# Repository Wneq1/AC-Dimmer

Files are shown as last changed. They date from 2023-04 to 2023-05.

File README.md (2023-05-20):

# AC-Dimmer

Power regulator for arduino 

In today's project, we will focus on building a power regulator using an Arduino microcontroller and a thyristor. Power regulators are commonly used to control the amount of electrical energy supplied to loads such as lamps, heaters, or motors, in order to adjust their brightness, temperature, or speed. By building your own power regulator using Arduino and a thyristor, you can create a cost-effective and customized solution for controlling AC loads in DIY projects or home automation systems. IF you wish to built one by yourselfe in this file, you can find a finished project in KiCad and short code in Arduino.

WARNING: THIS PROJECT INVOLVES HIGH VOLTAGES THAT CAN BE DANGEROUS TO LIFE AND HEALTH. 
YOU PERFORM THIS PROJECT AT YOUR OWN RISK AND RESPONSIBILITY.

To complete this project you will need:
Arduino or other microcontroller
* Fuse
* Resistors
    * 68k x2
    * 33k x2
    * 360 x1
    * 330 x2
    * 10k x5
    * 39 x1
* Capacitors
    * 0.01uF x1
    * 100nF x1
    * 25uF x1
* Optocoupler PC817
* Hi-link
* LM7805 (5V regulator)
* LED
* Optotriac MOC3041
* Pushbuttons
* OLED Display
* Thyristor BT138

Our system consists of several modules: 
* power module
* actuator module
* measurement module
* logic module



Short description of this project:

The power module is designed to deliver a stable 5V due to the current drawn by the circuit. I decided to use a pre-made Hi-Link power module, but if there is no need to support the interface (display buttons), a transformerless power supply can be used. The type of regulation used in the project is phase regulation. 
The disadvantage of this type of control is radio-electric interference, which appears when working with high-power receivers.

The measurement module consists of an optoelectronic component that is designed to detect the zero crossing of the input signal and then send information to the control module.

The output module consists of a triac that is turned on for a specified period by the microcontroller. In case the circuit needs to handle inductive loads, an additional capacitor and resistor should be added (refer to the datasheet).

The logic module consists of an Arduino microcontroller (or any other microcontroller that supports interrupts). The microcontroller operates based on interrupts (if zero crossing is detected, the microcontroller interrupts the currently running task and performs the interrupt function, i.e. turns on a timer that counts how long the output module should be turned on, and then turns off the triac).

Our device has 4 buttons, of which only 3 are used. One button is used to increase the power, the second to decrease it, and the third is the so-called "latch" button. There is also an LED used to indicate whether the latch is active. If the LED is on (button active), we can edit the power value by increasing or decreasing it. However, if the LED is off, we cannot edit the power value (even if we press other buttons, the power value will not change).

In AC-powered devices, power is closely related to the area under the sine wave applied to the input of our controlled system (e.g., a light bulb), and it is this area that can be regulated. However, in order to do this, we need a reference point. Since the signal present in the power socket is sinusoidal in nature, our reference point will be the zero crossing of the waveform, which will define how long our load will be energized. The longer the duration, the higher the power.

Now, let's do some math. Let's say the frequency of the power grid is 50 Hz, which means the period is f=1/T T=1/f=1/50=20[ms]. In each cycle, there are two peak values of the sine wave, so we reach the peak every 10 ms. If we manage to turn on the light bulb at the very beginning, it will receive 100% of the available power. If we turn it on halfway through (5 ms), it will receive 50% of the power, and if we turn it on towards the end of the 10 ms period, it will remain off (0% power).

Short description:

The blue waveform illustrates the mains voltage, while the orange waveform represents the response of the circuit to the previously applied power (response of the triac).
The waveform appearance for 100% power:



The waveform appearance for 50% power:



The waveform appearance for 25% power:



Below are some illustrative photos and link to video prezentation:



Short presentation on YouTube:
https://www.youtube.com/watch?v=zxgGnlvmVzU

In the files, you can also find another version of the Arduino code called 'Final Version,' where the only change is the selection mode of the controller values. However, the operating principle remains the same as in the previous version. You can find the link below.
Short presentation of Finall Version on YouTube:
https://www.youtube.com/watch?v=YGqYrHkOaR0

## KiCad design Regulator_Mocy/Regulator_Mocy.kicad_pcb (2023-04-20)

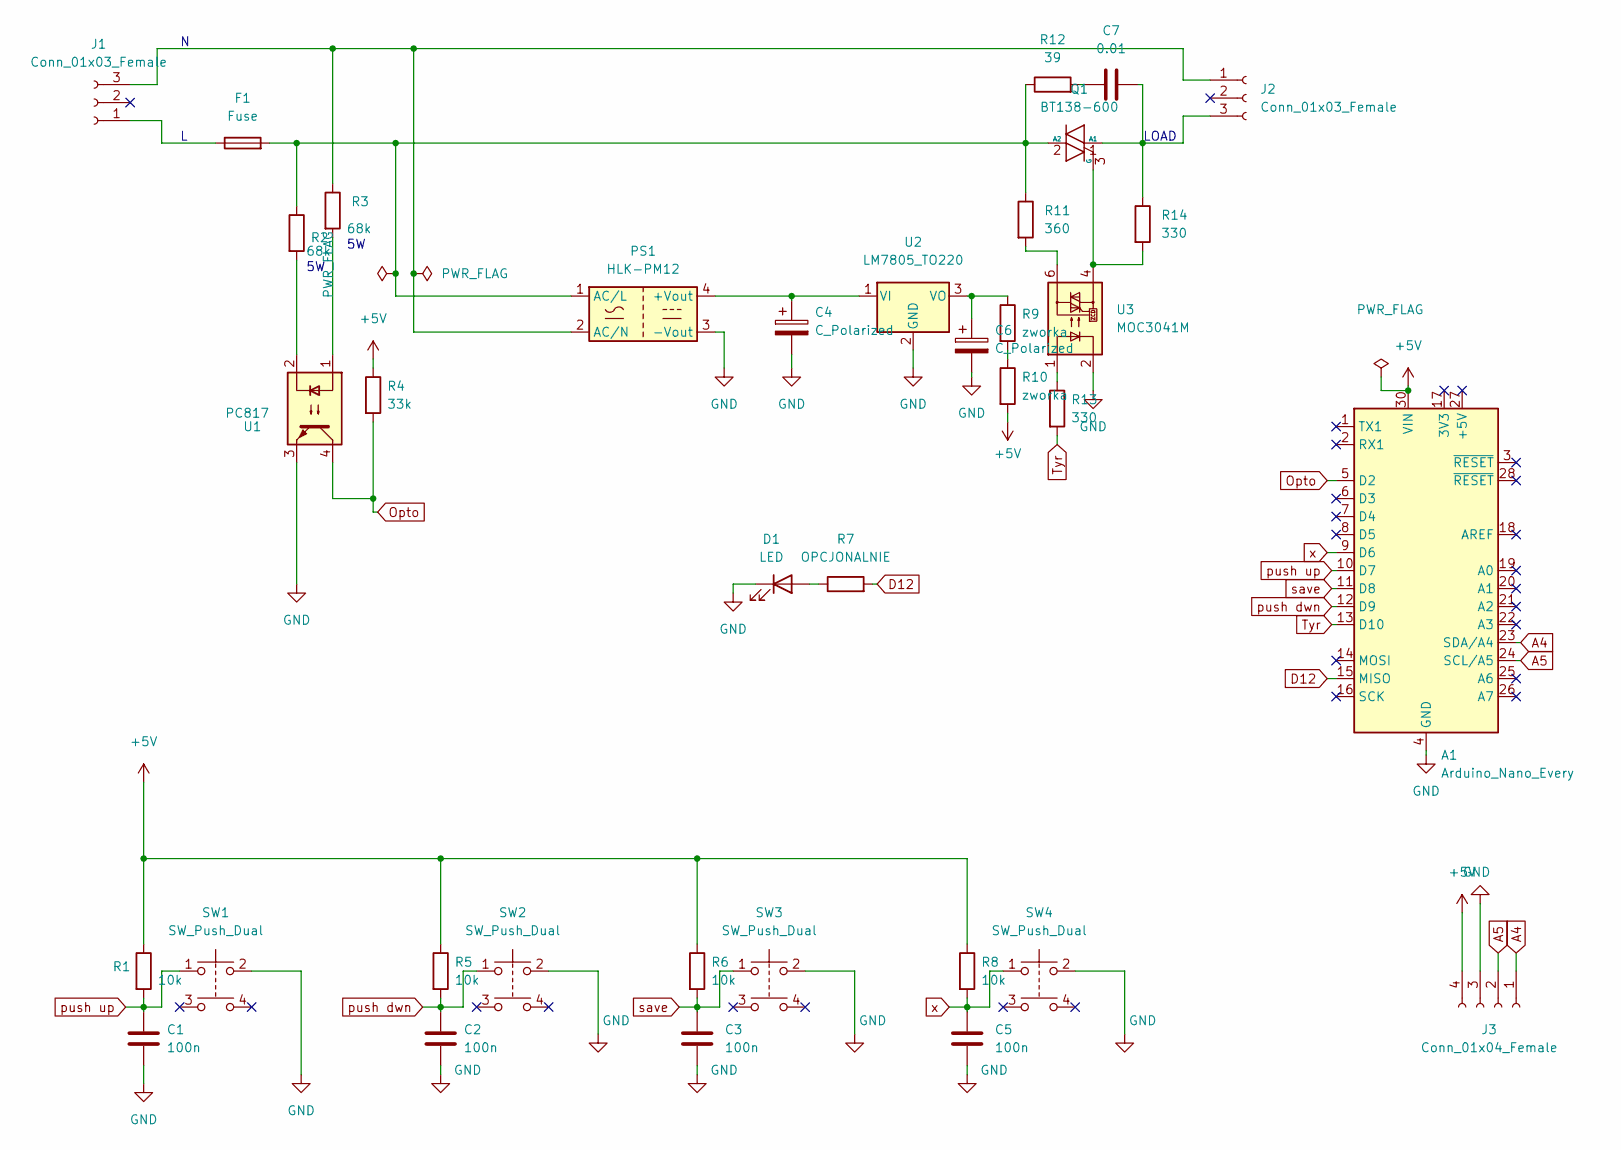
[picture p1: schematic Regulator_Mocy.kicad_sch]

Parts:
A1: Arduino_Nano_Every; Arduino_Nano
C1, C2, C3, C5: 100n; C_Axial_L3.8mm_D2.6mm_P10.00mm_Horizontal
C4, C6: C_Polarized; CP_Radial_D8.0mm_P3.80mm
C7: 0.01; C_Rect_L24.0mm_W10.1mm_P22.50mm_MKT
D1: LED; LED_D5.0mm
F1: Fuse; Fuseholder_Cylinder-5x20mm_Schurter_0031_8201_Horizontal_Op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
J1, J2: Conn_01x03_Female; Molex_KK-396_A-41792-0003_1x03_P3.96mm_Horizontal
J3: Conn_01x04_Female; PinHeader_1x04_P2.54mm_Vertical
PS1: HLK-PM12; Converter_ACDC_HiLink_HLK-PMxx
Q1: BT138-600; TO-220-3_Vertical
R1, R5, R6, R8: 10k; R_Axial_DIN0207_L6.3mm_D2.5mm_P10.16mm_Horizontal
R2, R3: 68k; R_Axial_Power_L25.0mm_W9.0mm_P27.94mm
R4: 33k; R_Axial_DIN0207_L6.3mm_D2.5mm_P10.16mm_Horizontal
R7: OPCJONALNIE; R_Axial_DIN0207_L6.3mm_D2.5mm_P10.16mm_Horizontal
R9, R10: zworka; R_Axial_DIN0204_L3.6mm_D1.6mm_P5.08mm_Vertical
R11: 360; R_Axial_DIN0207_L6.3mm_D2.5mm_P10.16mm_Horizontal
R12: 39; R_Axial_Power_L25.0mm_W9.0mm_P27.94mm
R13, R14: 330; R_Axial_DIN0207_L6.3mm_D2.5mm_P10.16mm_Horizontal
SW1, SW2, SW3, SW4: SW_Push_Dual; SW_PUSH_6mm_H7.3mm
U1: PC817; DIP-4_W7.62mm
U2: LM7805_TO220; TO-220-3_Vertical
U3: MOC3041M; DIP-6_W7.62mm

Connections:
+5V: A1.30 (VIN), J3.4, R1.1, R4.1, R5.1, R6.1, R8.1, R10.2
A4: A1.23 (SDA/A4), J3.1
A5: A1.24 (SCL/A5), J3.2
D12: A1.15 (MISO), R7.2
GND: A1.4 (GND), A1.29 (GND), C1.2, C2.2, C3.2, C4.2, C5.2, C6.2, D1.1 (K), J3.3, PS1.3 (-Vout), SW1.2, SW2.2, SW3.2, SW4.2, U1.3, U2.2 (GND), U3.2
unnamed: C4.1, PS1.4 (+Vout), U2.1 (VI)
unnamed: C6.1, R9.1, U2.3 (VO)
unnamed: C7.1, R12.2
unnamed: C7.2, J2.3, Q1.1 (A1), R14.1
unnamed: D1.2 (A), R7.1
unnamed: F1.1, J1.1
unnamed: F1.2, PS1.1 (AC/L), Q1.2 (A2), R2.1, R11.1, R12.1
unnamed: J1.3, J2.1, PS1.2 (AC/N), R3.1
unnamed: Q1.3 (G), R14.2, U3.4
unnamed: R2.2, U1.2
unnamed: R3.2, U1.1
unnamed: R9.2, R10.1
unnamed: R11.2, U3.6
unnamed: R13.1, U3.1
Opto: A1.5 (D2), R4.2, U1.4
Tyr: A1.13 (D10), R13.2
push dwn: A1.12 (D9), C2.1, R5.2, SW2.1
push up: A1.10 (D7), C1.1, R1.2, SW1.1
save: A1.11 (D8), C3.1, R6.2, SW3.1
x: A1.9 (D6), C5.1, R8.2, SW4.1

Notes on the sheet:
LOAD

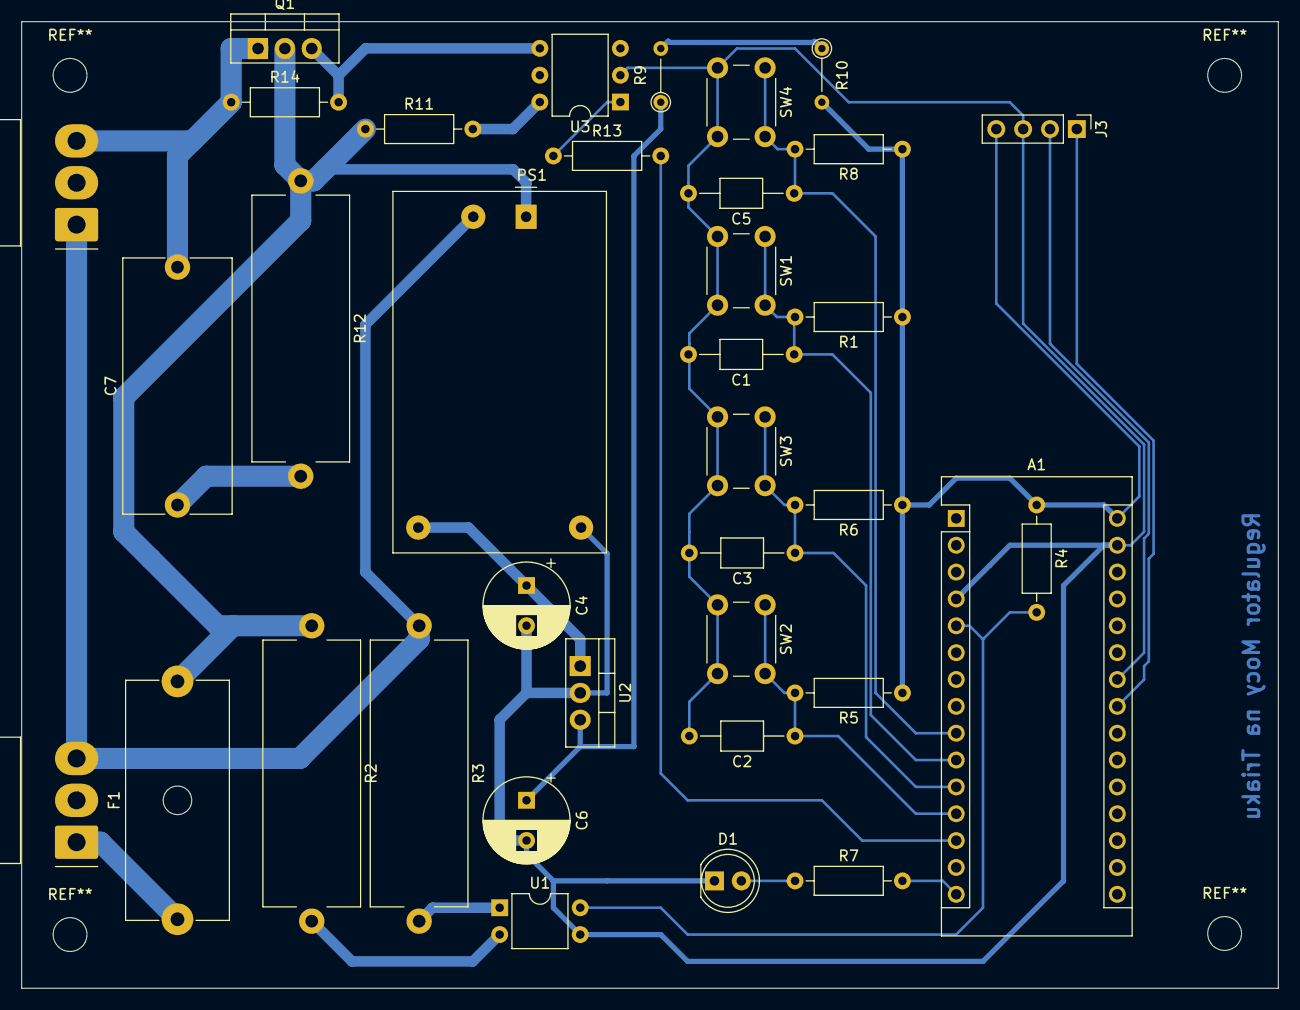
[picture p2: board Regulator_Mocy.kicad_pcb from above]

Board: 2 copper layers, 118.9 x 91.4 mm, 36 parts (0 on the bottom side), 25 nets.

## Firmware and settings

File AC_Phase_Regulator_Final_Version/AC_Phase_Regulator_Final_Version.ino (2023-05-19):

#include <TimerOne.h>
#include <Wire.h>
#include <Adafruit_GFX.h>
#include <Adafruit_SSD1306.h>

#define OLED_RESET 4
Adafruit_SSD1306 display(OLED_RESET);

int LED = 12;           // signalization LED
int previous_save_value = 0;
int set_value = 0;
int x = 128;

int add_button = 9;
int subtract_button = 7;
int save_button = 8;
int save_button_state = HIGH;
int last_save_button_state = HIGH;
bool save = false;

int Triac = 10; //AC Load

int inc = 1;

volatile int i = 0;
volatile boolean zero_crossing = false; //zero crosing value
int value = 128;           //value for operating triac
int frequency_step = 75;   // 50Hz -> 75 || 60Hz -> 65

/* It is calculated based on the frequency of the power supply and the desired brightness level.
 *
 * The program relies on two zero-crossing points during one cycle, which is either for 120Hz and 60Hz or for 100Hz and 50Hz.
 *
 * To determine the frequency step, divide the duration of a full signal half-cycle in microseconds by the number of brightness levels per step.
 *
 * (120Hz = 8,333μs) -> 128 steps yield 65μs
 * (100Hz = 10,000μs) -> 128 steps yield 75μs
 */



void setup() {
  Serial.begin(9600);
  pinMode(Triac, OUTPUT);
  pinMode(LED, OUTPUT);
  pinMode(add_button, INPUT_PULLUP);
  pinMode(subtract_button, INPUT_PULLUP);
  pinMode(save_button, INPUT_PULLUP);

  attachInterrupt(0, detect_zero_crossing, RISING);   // zero crossing detector on pin numb. 2
  Timer1.initialize(frequency_step);
  Timer1.attachInterrupt(check_value, frequency_step);

  display.begin(SSD1306_SWITCHCAPVCC, 0x3C);
  display.display();
  display.clearDisplay();
}

void detect_zero_crossing() {
  zero_crossing = true;
  i = 0;
  digitalWrite(Triac, LOW);
}

void check_value() {
  if (zero_crossing == true) {
    if (i >= value) {
      digitalWrite(Triac, HIGH);
      i = 0;
      zero_crossing = false;
    }
    else {
      i++;
    }
  }
}

int AddButton(int add_button) {
  if (digitalRead(add_button) == LOW) {
    if (x < 128) {
      x = x + 1;
      delay(10);
    }
  }
  return x;
}

int SubtractButton(int subtract_button) {
  if (digitalRead(subtract_button) == LOW) {
    if (value > 0) {
      x = x - 1;
      delay(10);
    }
  }
  return x;
}

bool SaveButton(int save_button) {
  save_button_state = digitalRead(save_button);
  if (save_button_state == LOW && last_save_button_state == HIGH) {
    save = !save;
  }
  last_save_button_state = save_button_state;
  delay(10);
  return save;
}

void test() {
  value += inc;
  if ((value >= 128) || (value <= 0))
    inc *= -1;
  delay(20);
}

void loop() {
  int save_button_state = digitalRead(save_button);

  if (save_button_state == LOW && last_save_button_state == HIGH) {
    save = !save;
    if (save == 0) {
      value = x;
    }
  }

  last_save_button_state = save_button_state;

  if (save == 1) {
    digitalWrite(LED, HIGH);
    
    x = AddButton(add_button);
    x = SubtractButton(subtract_button);

    display.clearDisplay();
    display.setTextSize(3);
    display.setTextColor(WHITE);
    display.setCursor(40, 0);
    display.print(map(x, 128, 0, 0, 100));
    display.print("%");

    display.setTextSize(1);
    display.setTextColor(WHITE);
    display.setCursor(20, 25);
    display.print("Phase regulation");
    display.display();
  } else if (save == 0 && set_value == 0) {
    for (int i = 0; i < x; i++) {
      value++;
    }
    set_value = 1;

    display.clearDisplay();
    display.setTextSize(3);
    display.setTextColor(WHITE);
    display.setCursor(40, 0);
    display.print(map(x, 128, 0, 0, 100));
    display.print("%");

    display.setTextSize(1);
    display.setTextColor(WHITE);
    display.setCursor(20, 25);
    display.print("Phase regulation");
    display.display();
  }

  if (save == 0) {
    digitalWrite(LED, HIGH);
    delay(500);
    digitalWrite(LED, LOW);
    delay(500);
  }

  Serial.println("X " + String(x) + " Value " + value);
}

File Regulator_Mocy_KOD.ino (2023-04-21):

#include <TimerOne.h>                    // library for phase control

#include <Wire.h>                         // display initialization
#include <Adafruit_GFX.h>
#include <Adafruit_SSD1306.h>
#define OLED_RESET 4
Adafruit_SSD1306 display(OLED_RESET);
#if (SSD1306_LCDHEIGHT != 64)
//#error("Height incorrect, please fix Adafruit_SSD1306.h!");
#endif/

int LED = 12;

int button_add = 9;                   // button to increase power

int button_subtract = 7;                 // button to decrease power

int button_save = 8;                   // save button
int button_save_state = HIGH;
int last_button_save_state = HIGH;
int save = 0;

int Triac = 10;                          // pin to control the triac

int inc = 1;                                // test variable

volatile int i = 0;                         // counts time since zero crossing CHYBA?!?
volatile boolean zero_crossing = 0;            // variable for zero crossing detection
int value = 128;                            // variable for changing power value 128 - Off (0%), 0 - On (100%)
int frequency_step = 75;                        // For 60 Hz should be changed to 65, determines time before activation

/* It is calculated based on the frequency of the supply voltage and the brightness level needed
 *
 * The program is based on two zero crossings during one cycle, which means for 120Hz and 60Hz or for 100Hz and 50Hz
 *
 * To determine the frequency step, divide the length of a full half-cycle of the signal in microseconds by the number of brightness levels per step
 *
 * (120Hz =  8,333uS) -> 128 steps gives 65uS
 * (100Hz = 10,000uS) -> 128 steps gives 75uS
 */

void setup() {

  pinMode(Triac, OUTPUT);                // set triac as output

  pinMode(button_add, INPUT_PULLUP);  // connect buttons with pull-up resistors
  pinMode(button_subtract, INPUT_PULLUP);
  pinMode(button_save, INPUT_PULLUP);


  attachInterrupt(0, detect_zero_crossing, RISING);  // function responsible for detecting zero crossing connected to pin D2 -> (0)
  Timer1.initialize(frequency_step);                    // initialize timer for the required frequency
  Timer1.attachInterrupt(check_value, frequency_step);    // function checks if the triac should be turned on at the right moment and works in milliseconds

  display.begin(SSD1306_SWITCHCAPVCC, 0x3C);  // initialize display via I2C with address 0x3D and resolution of 128x64
  display.display();
  display.clearDisplay();

}

void detect_zero_crossing() {   // function for controlling the triac when a zero crossing is detected
  zero_crossing = true;
  i = 0;
  digitalWrite(Triac, LOW);
}

void check_value() {            // function responsible for checking zero crossing
  if (zero_crossing == true) {
    if (i >= value) {
      digitalWrite(Triac, HIGH);
      i = 0;
      zero_crossing = false;
    }
    else {
      i++;
    }
  }
}

int Button_Add(int button_add, int button_save){ // Button to increase the value of the variable "value" representing power
  if(save==1){
    if (digitalRead(button_add) == LOW) { 
      if (value < 128) { 
        value = value + 1;
        delay(10);
      }
    }
    return(value);
  }
}

int Button_Subtract(int button_subtract, int button_save){ // Button to decrease the value of the variable "value" representing power
  if(save==1){
    if (digitalRead(button_subtract) == LOW) { 
      if (value > 0) { 
        value=value - 1; 
        delay(10);
      }
    }
    return(value);
  }
}

int Button_Save(int button_save){ // Button that enables changing the power only after pressing it
  button_save_state = digitalRead(button_save);
  if(button_save_state == LOW && last_button_save_state == HIGH){
    save = 1 - save;
  }
  last_button_save_state = button_save_state;
  delay(10);
  return (save);
} 

void test(){ // Sequentially turns on and off a load
  value += increment;
  if((value >= 128) || (value <= 0))
    increment *= -1;
  delay(20);
}

void loop() { 
  
  Button_Save(button_save); // Initialize functions to control buttons
  Button_Add(button_add, button_save);
  Button_Subtract(button_subtract, button_save);
 
  display.clearDisplay(); // Initialize the display
  display.setTextSize(4);
  display.setTextColor(WHITE);
  display.setCursor(24,0);
  display.print(map(value, 128, 0, 0, 100)); 
  display.print("%");
  display.display();
  
  if (save == 1){
    digitalWrite(LED, HIGH);
  }
  else
    digitalWrite(LED, LOW);
}
